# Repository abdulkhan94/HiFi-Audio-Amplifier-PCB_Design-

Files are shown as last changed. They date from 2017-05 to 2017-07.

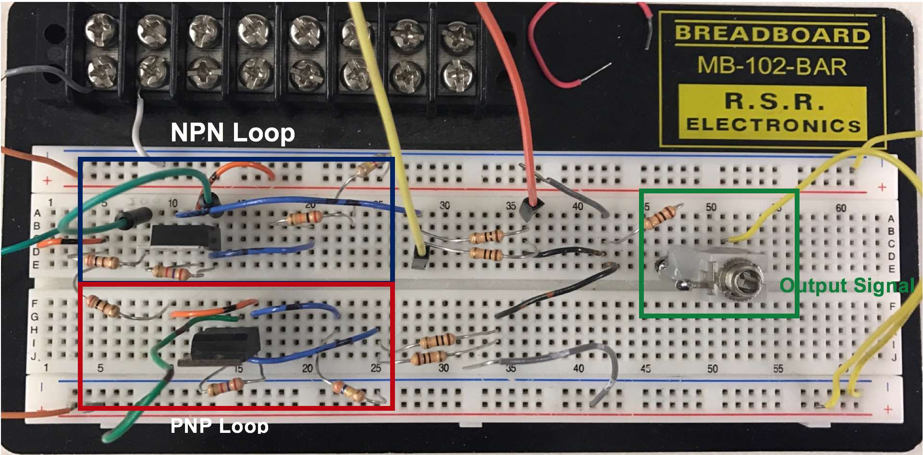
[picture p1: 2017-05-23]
Documents & Simulations/FDR/Proto_anote_v2.png

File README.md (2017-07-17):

# Transparent HiFi Audio Amplifier for Headphones
## Introduction
The goal of our Transparent HiFi USB Audio Amplifier system is to take in a audio signal via USB, allow the user to modify amplifier and volume controls, and to hear the modified audio signal through headphones. Our system specifications are for our design to not produce a DC offset that’s greater than 20mV, to not produce excessive power spikes greater than 50mV, have an output impedance of less than 2 ohms, and to support 8 specific headphones with a range of impedances from 16 to 600 ohms. The left and right audio signals must have flat frequency responses (+/-2.5dB), linear/flat phase responses without being set at 0dB, noise under -105dBv (-103dBu) and distortion under 1% THd into 150 ohms at 1Vrms. Lastly, the power amplifier must have a slew of under 3V/us by a square wave of 600 ohms. 

## Power Amplifier
The power amplifier subsystem will get a 1 V pk-pk signal input from the Amplifier controls subsystem and will amplify that to output analog audio signal across various headphones. All parts of the subsystem will be powered by +13/-13 DC Voltage signal. The subsystem consists of two different parts to achieve amplification of both current and voltage.
The first stage of the design consists of a preamplifier design. This is essentially a Class A audio amplifier which is implemented in order to boost the voltage of the 1 V pk-pk signal that the subsystem receives as input from the amplifier controls subsystem. A major design consideration that has been made here revolves around amplifying voltage to the adequate level while maintaining low noise in the signal. The design consists of two biasing resistors followed by a NPN transistor. This part of the design is powered by a +13V DC power rail. 
The next step of the design consists of the power amplifier which amplifies the current. This part of the subsystem is required to have enough current in order to drive the output across the headphones. A class AB amplifier design has been implemented here in order to achieve the adequate current amplification. This design also consists of two biasing resistors for each transistor and is powered by +/- 13V DC power rails.

## Current Status
* All subsytems of the design have been finalised and layed out on PCB's. 
* All subsystems integrated and fully functional.

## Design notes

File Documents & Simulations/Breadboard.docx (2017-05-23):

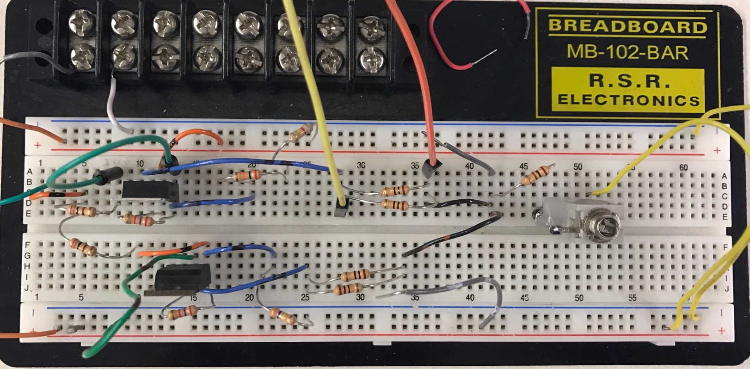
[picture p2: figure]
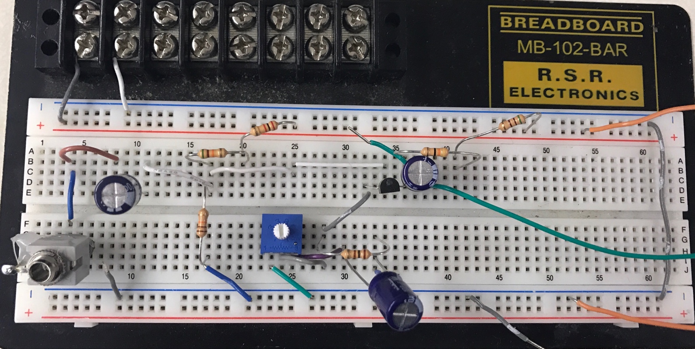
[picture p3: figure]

Output Signal

PNP Loop

NPN Loop

Input Signal

Bias Resistors

Output to 2nd Stage

NPN Transistor

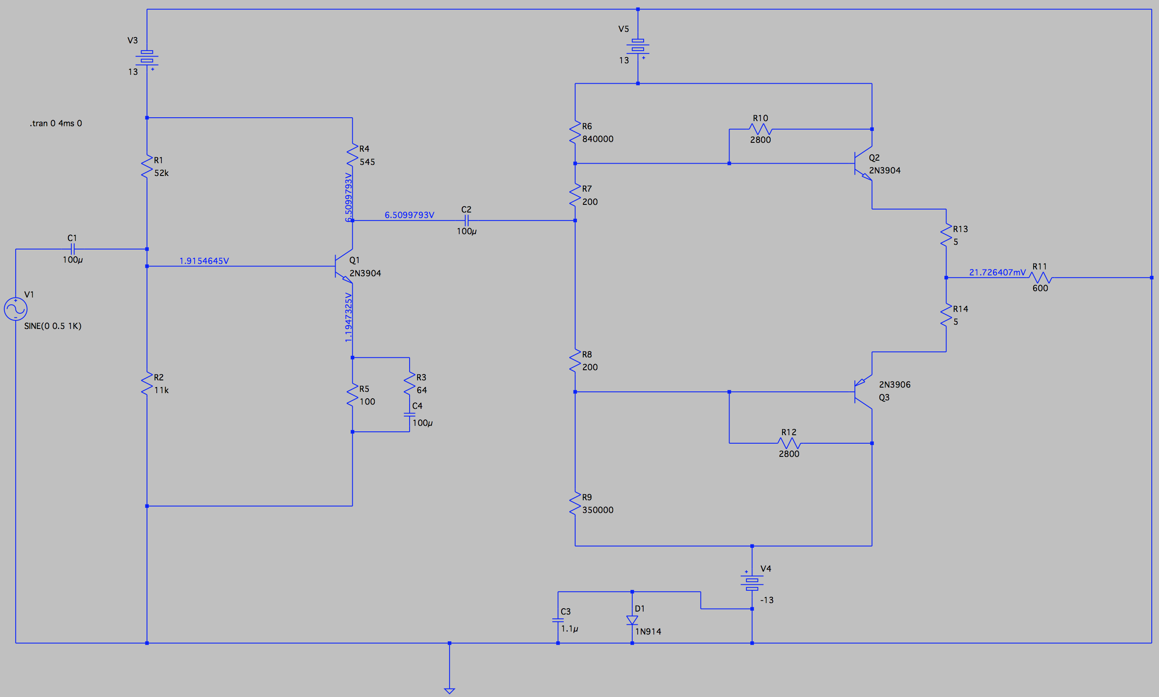
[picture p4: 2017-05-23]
Documents & Simulations/ManagerMeeting2/Schematic_final.png

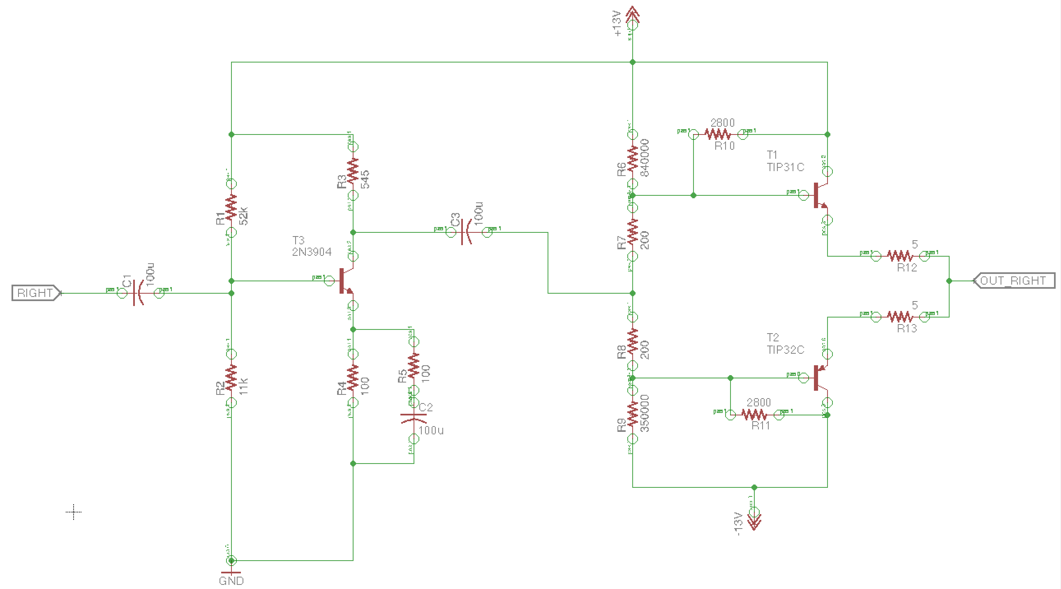
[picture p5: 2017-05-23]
Documents & Simulations/FDR/Final_Schematic.png

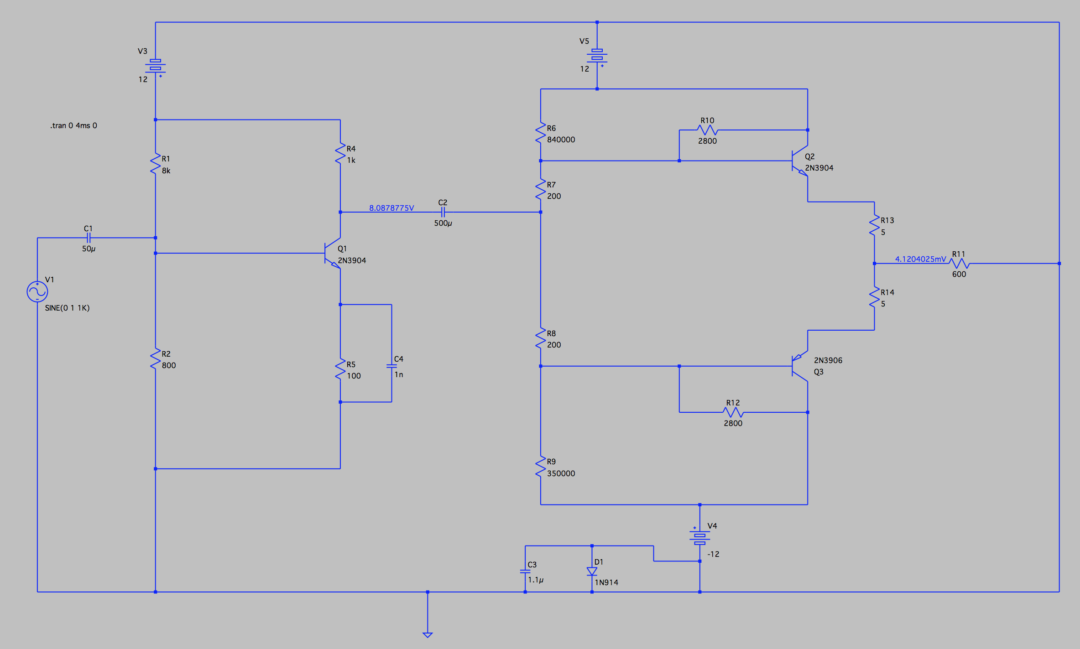
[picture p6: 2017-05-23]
Documents & Simulations/Schematic_v2.png

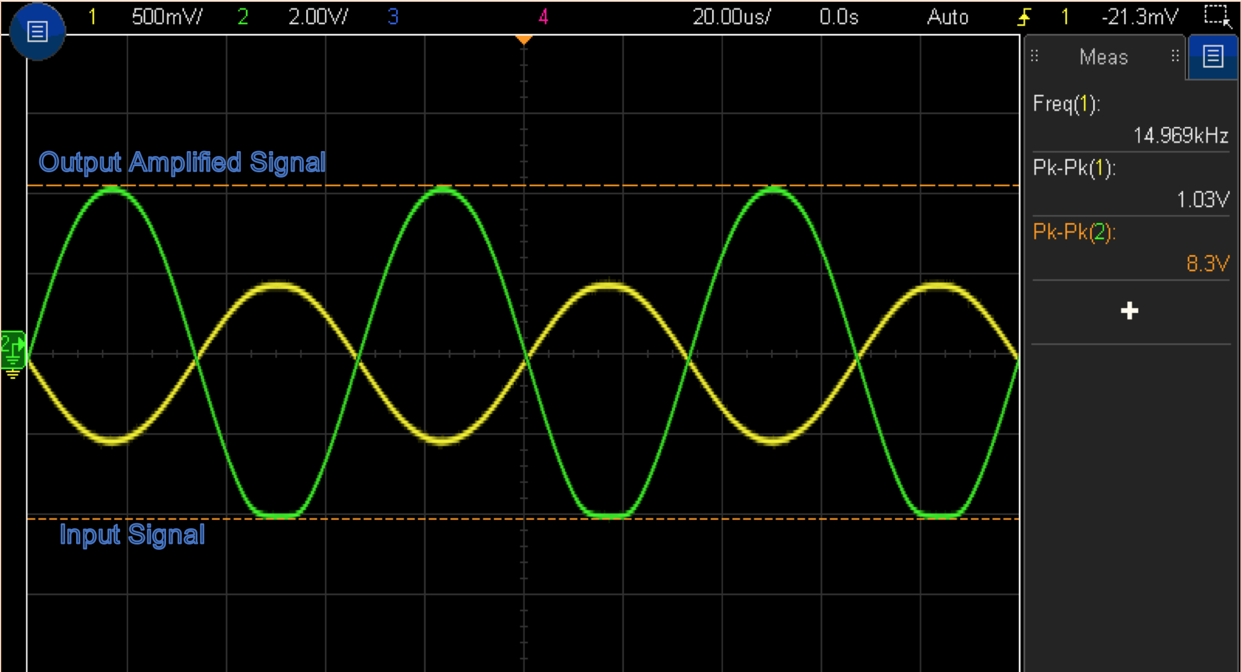
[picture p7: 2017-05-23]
Documents & Simulations/FDR/PowerAmp_15Khhz.png

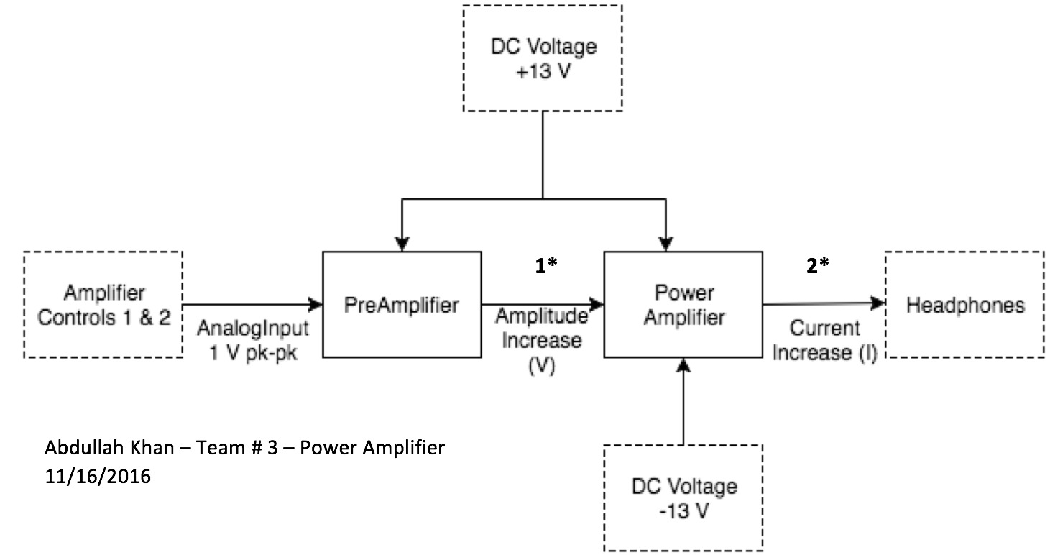
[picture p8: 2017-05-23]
Documents & Simulations/FDR/Block.png

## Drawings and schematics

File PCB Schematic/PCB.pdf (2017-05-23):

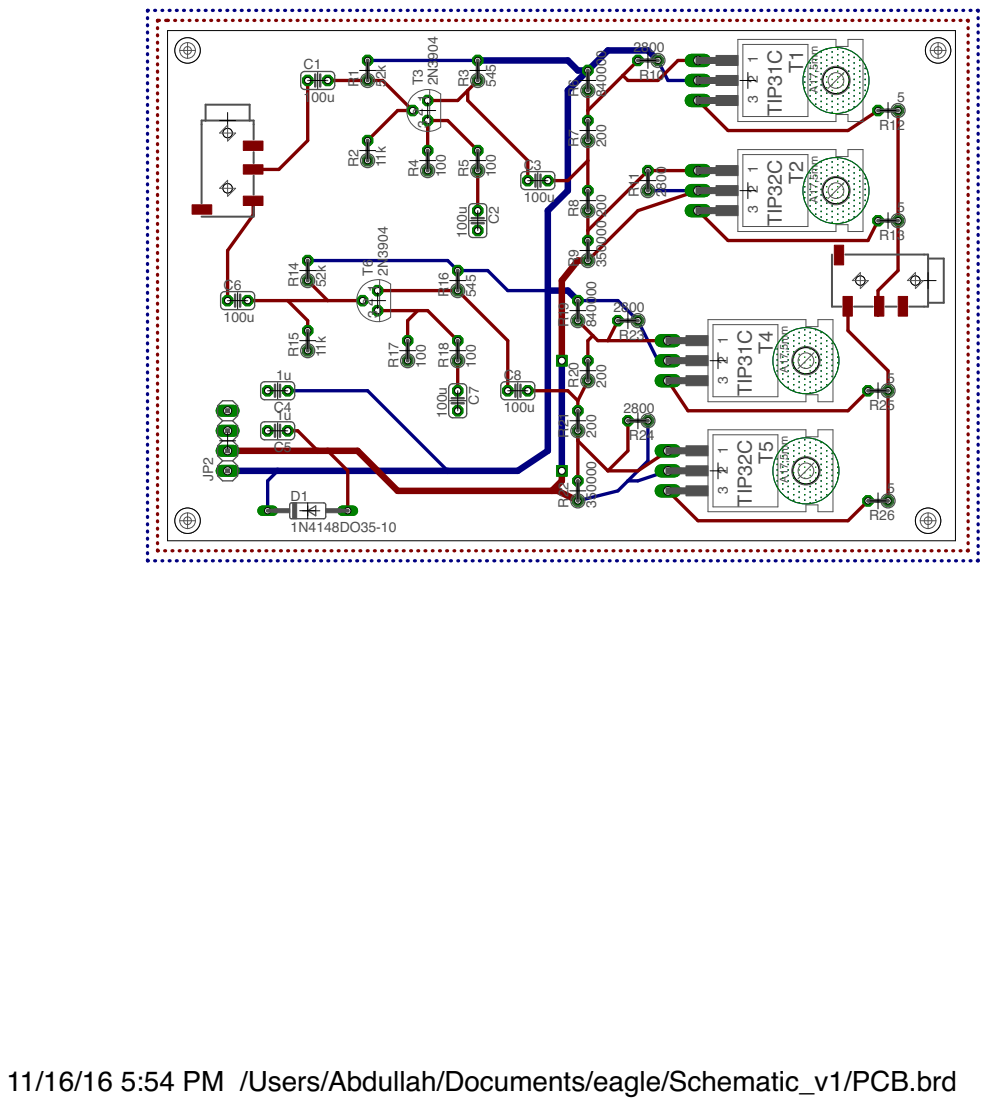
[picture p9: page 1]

11/16/16 5:54 PM /Users/Abdullah/Documents/eagle/Schematic_v1/PCB.brd

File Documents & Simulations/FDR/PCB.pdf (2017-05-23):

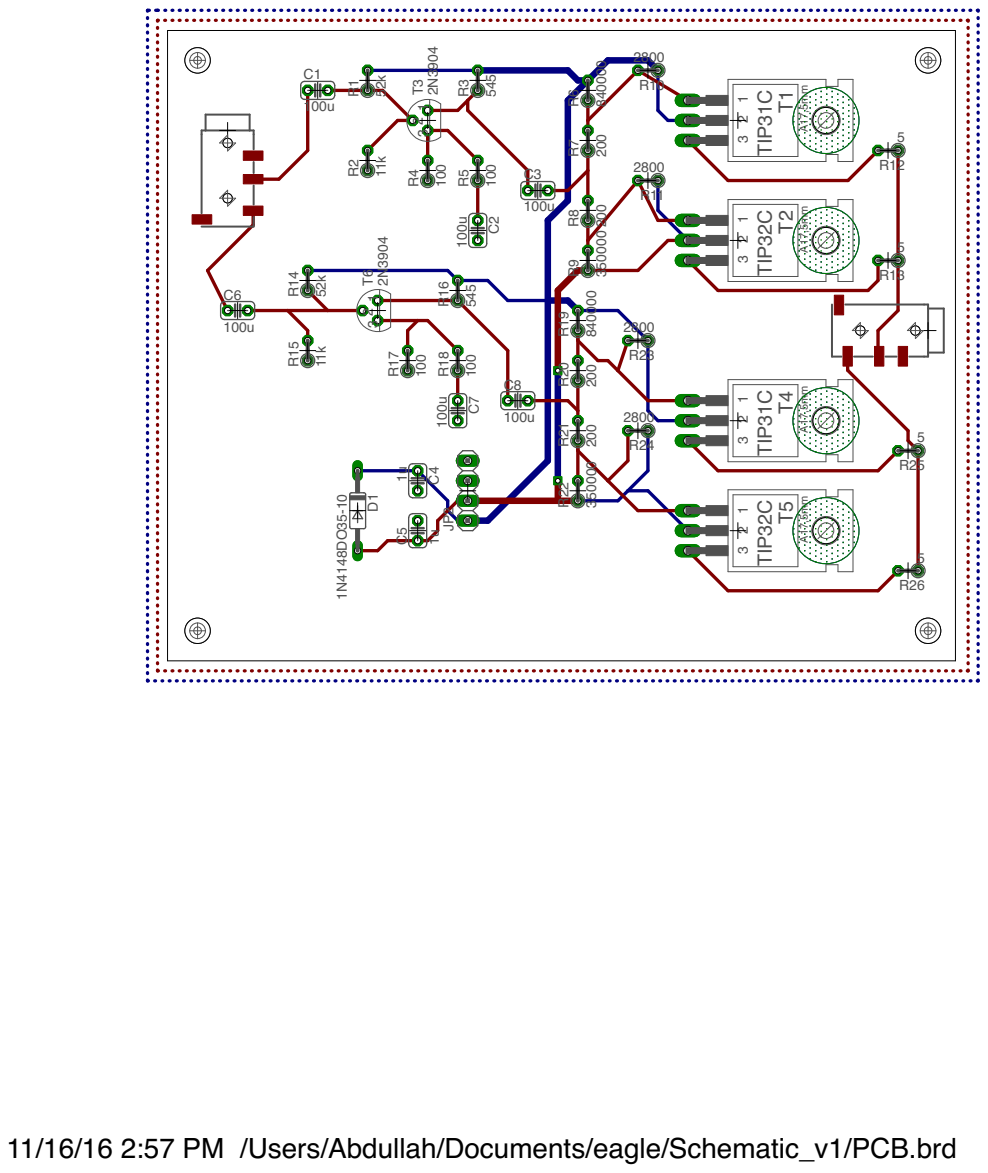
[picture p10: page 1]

11/16/16 2:57 PM /Users/Abdullah/Documents/eagle/Schematic_v1/PCB.brd

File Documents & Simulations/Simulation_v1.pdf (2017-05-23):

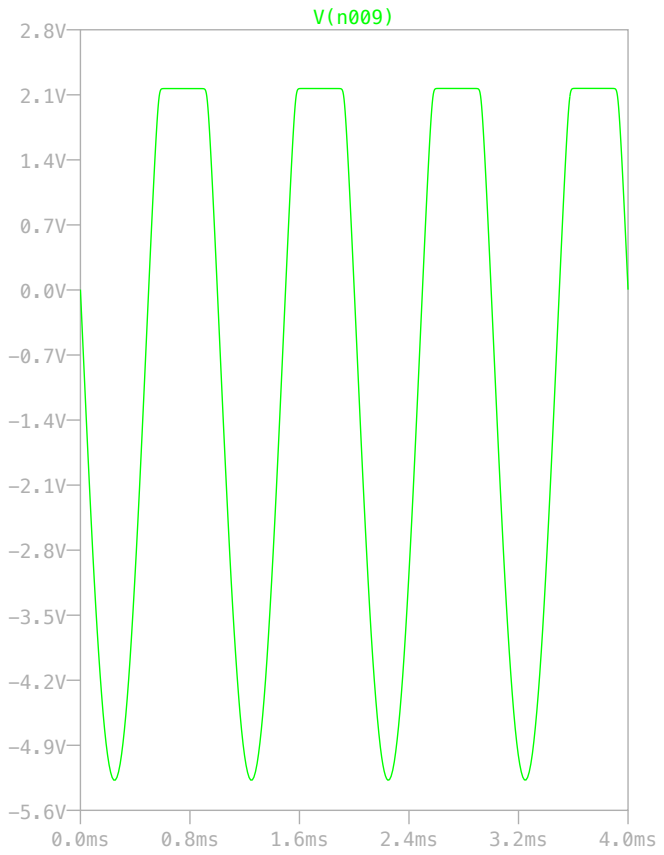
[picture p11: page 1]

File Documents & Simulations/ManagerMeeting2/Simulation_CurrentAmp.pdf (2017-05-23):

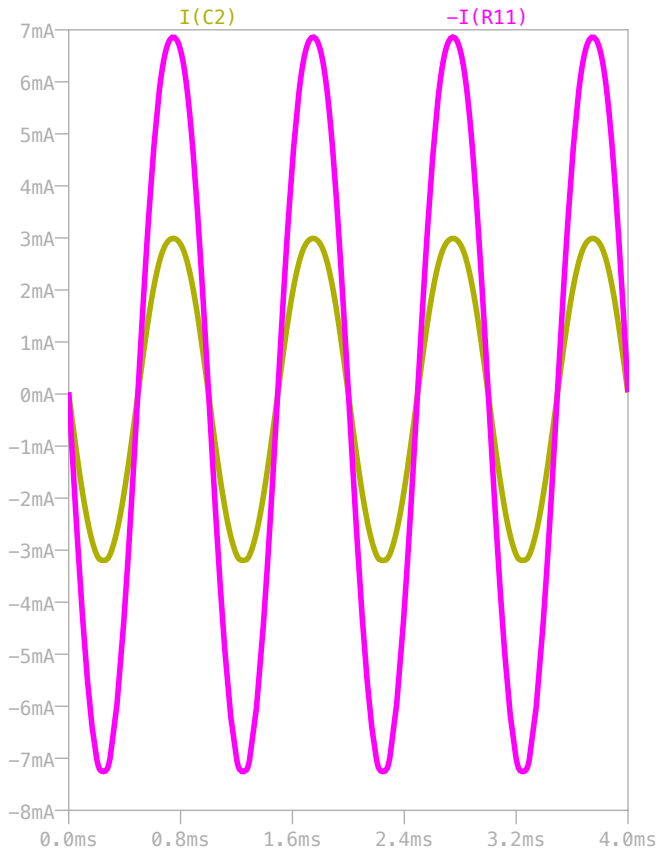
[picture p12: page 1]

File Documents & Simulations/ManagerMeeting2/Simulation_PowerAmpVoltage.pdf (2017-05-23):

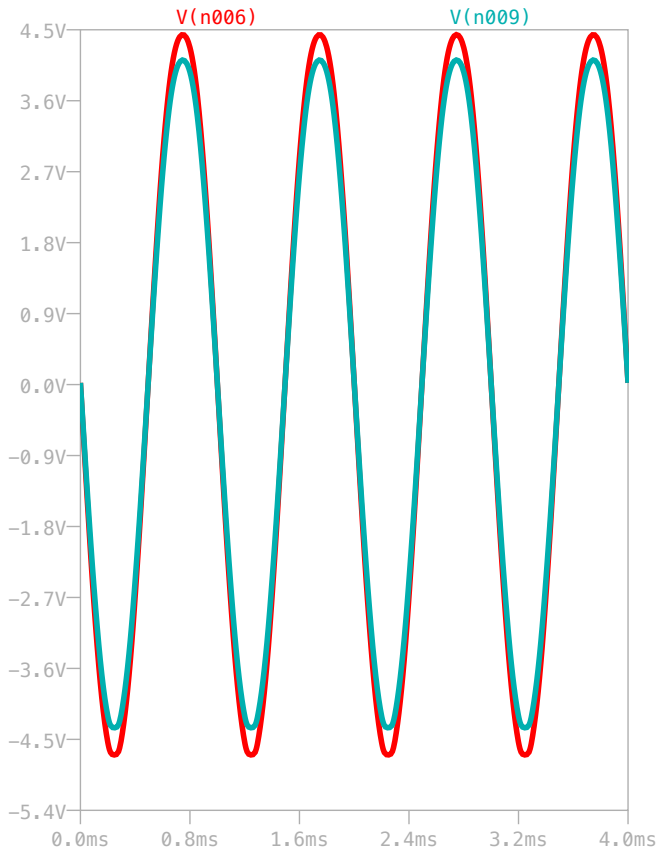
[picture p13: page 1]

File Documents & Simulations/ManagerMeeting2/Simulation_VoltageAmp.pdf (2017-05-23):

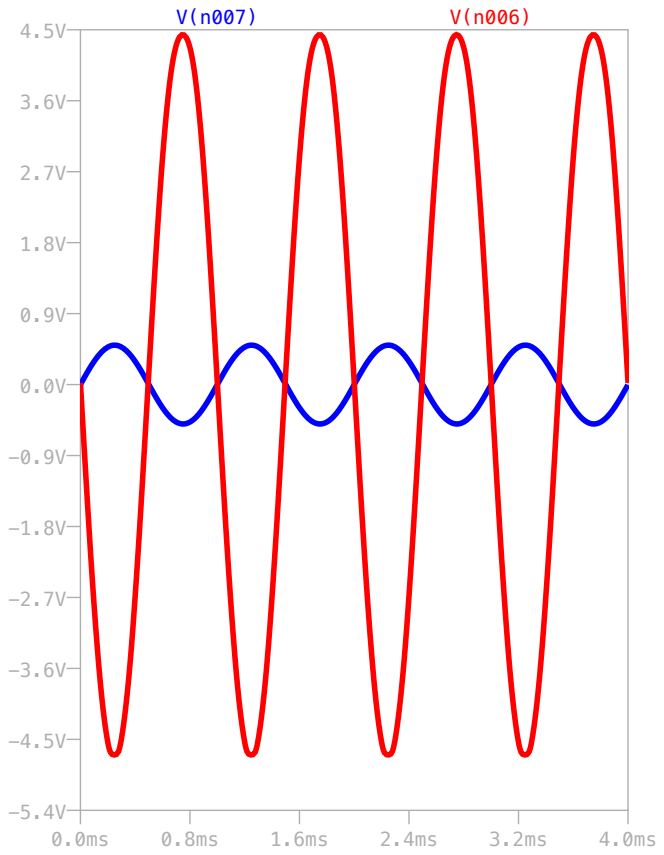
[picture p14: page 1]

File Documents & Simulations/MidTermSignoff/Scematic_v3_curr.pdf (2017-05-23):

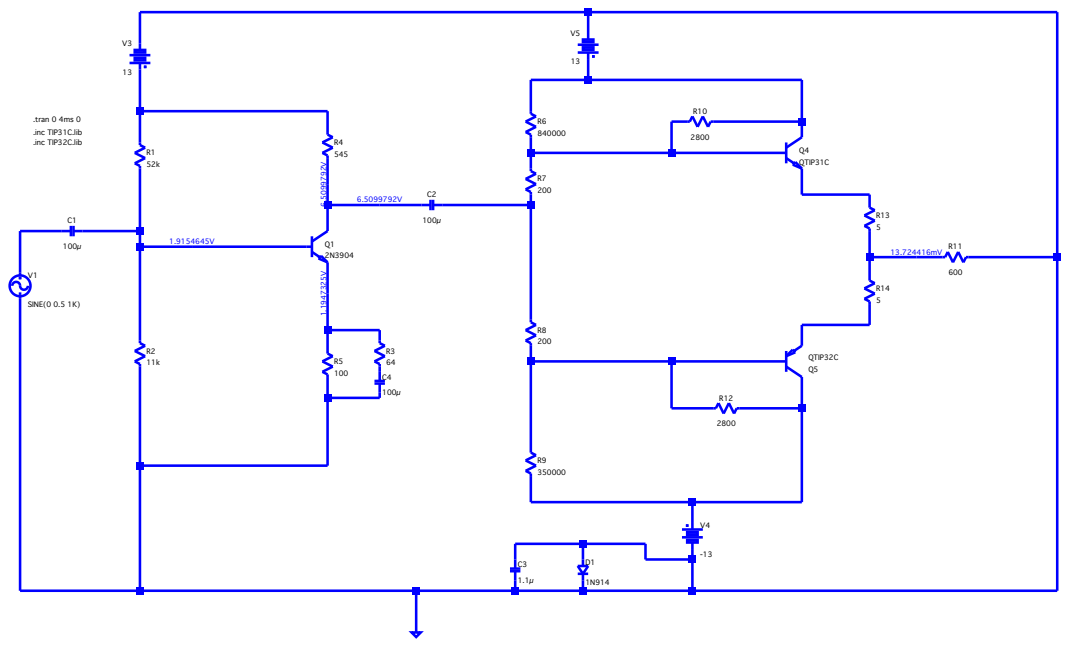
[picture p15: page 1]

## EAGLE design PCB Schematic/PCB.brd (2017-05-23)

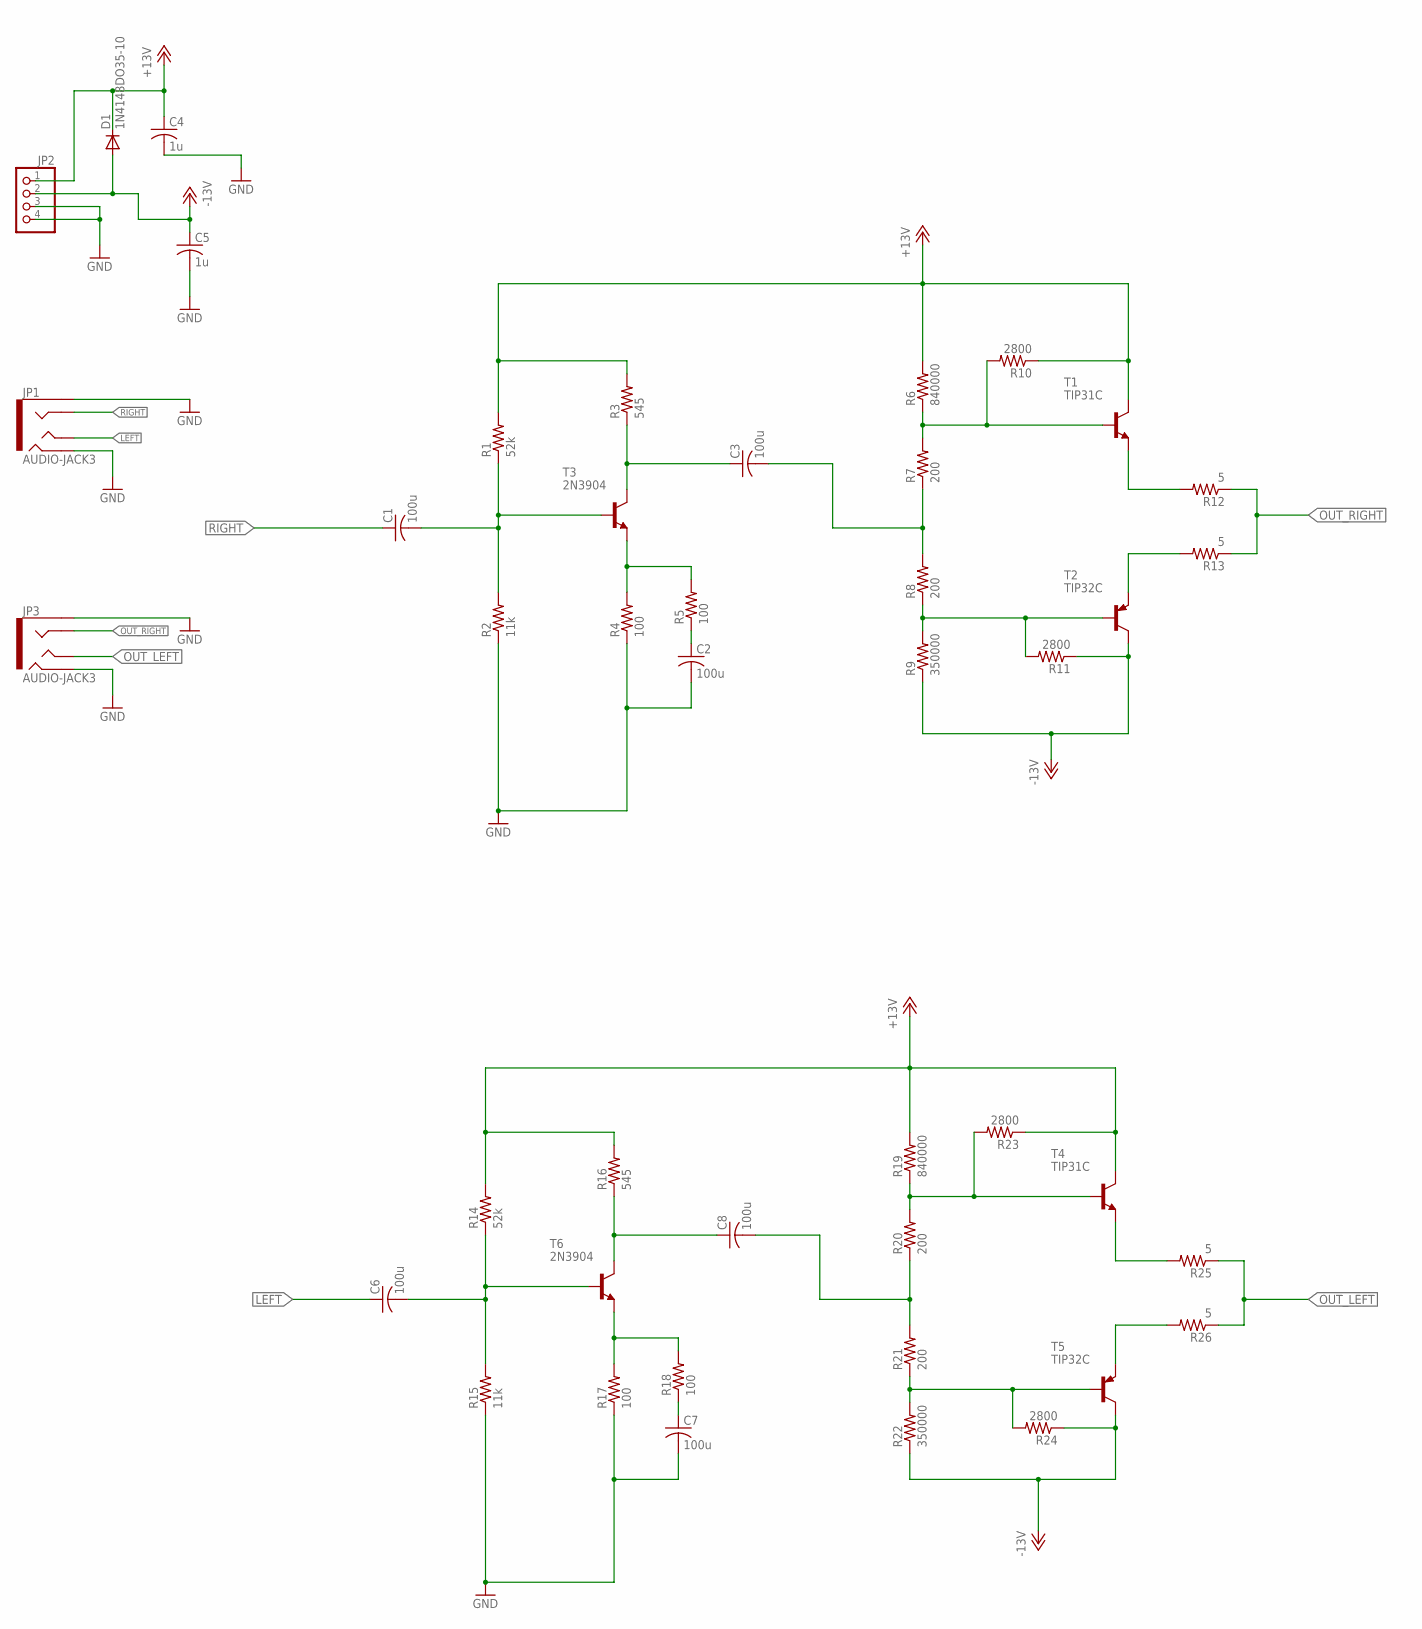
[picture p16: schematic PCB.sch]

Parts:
C1, C2, C3, C6, C7, C8: 100u; C025-024X044
C4, C5: 1u; C025-024X044
D1: 1N4148DO35-10; DO35-10
JP1, JP3: AUDIO-JACK3; AUDIO-JACK-TRRS-SMD
JP2: PINHD-1X4; 1X04
R1, R14: 52k; 0204V
R2, R15: 11k; 0204V
R3, R16: 545; 0204V
R4, R5, R17, R18: 100; 0204V
R6, R19: 840000; 0204V
R7, R8, R20, R21: 200; 0204V
R9, R22: 350000; 0204V
R10, R11, R23, R24: 2800; 0204V
R12, R13, R25, R26: 5; 0204V
T1, T4: TIP31C; TO220
T2, T5: TIP32C; TO220
T3, T6: 2N3904; TO92

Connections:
+13V: C4.1, D1.C, JP2.1, R1.2, R3.2, R6.2, R10.1, R14.2, R16.2, R19.2, R23.1, T1.2 (C), T4.2 (C)
-13V: C5.1, D1.A, JP2.2, R9.1, R11.1, R22.1, R24.1, T2.2 (C), T5.2 (C)
GND: C2.2, C4.2, C5.2, C7.2, JP1.EARTH, JP1.RING2, JP2.3, JP2.4, JP3.EARTH, JP3.RING2, R2.1, R4.1, R15.1, R17.1
LEFT: C6.1, JP1.TIP
unnamed: C1.2, R1.1, R2.2, T3.2 (B)
unnamed: C3.1, R3.1, T3.1 (C)
unnamed: C6.2, R14.1, R15.2, T6.2 (B)
unnamed: R4.2, R5.2, T3.3 (E)
unnamed: R6.1, R7.2, R10.2, T1.1 (B)
unnamed: C2.1, R5.1
unnamed: C3.2, R7.1, R8.2
unnamed: R8.1, R9.2, R11.2, T2.1 (B)
unnamed: R12.2, T1.3 (E)
unnamed: R13.2, T2.3 (E)
unnamed: C8.1, R16.1, T6.1 (C)
unnamed: R17.2, R18.2, T6.3 (E)
unnamed: C7.1, R18.1
unnamed: R19.1, R20.2, R23.2, T4.1 (B)
unnamed: C8.2, R20.1, R21.2
unnamed: R21.1, R22.2, R24.2, T5.1 (B)
unnamed: R25.2, T4.3 (E)
unnamed: R26.2, T5.3 (E)
OUT_LEFT: JP3.TIP, R25.1, R26.1
OUT_RIGHT: JP3.RING1, R12.1, R13.1
RIGHT: C1.1, JP1.RING1

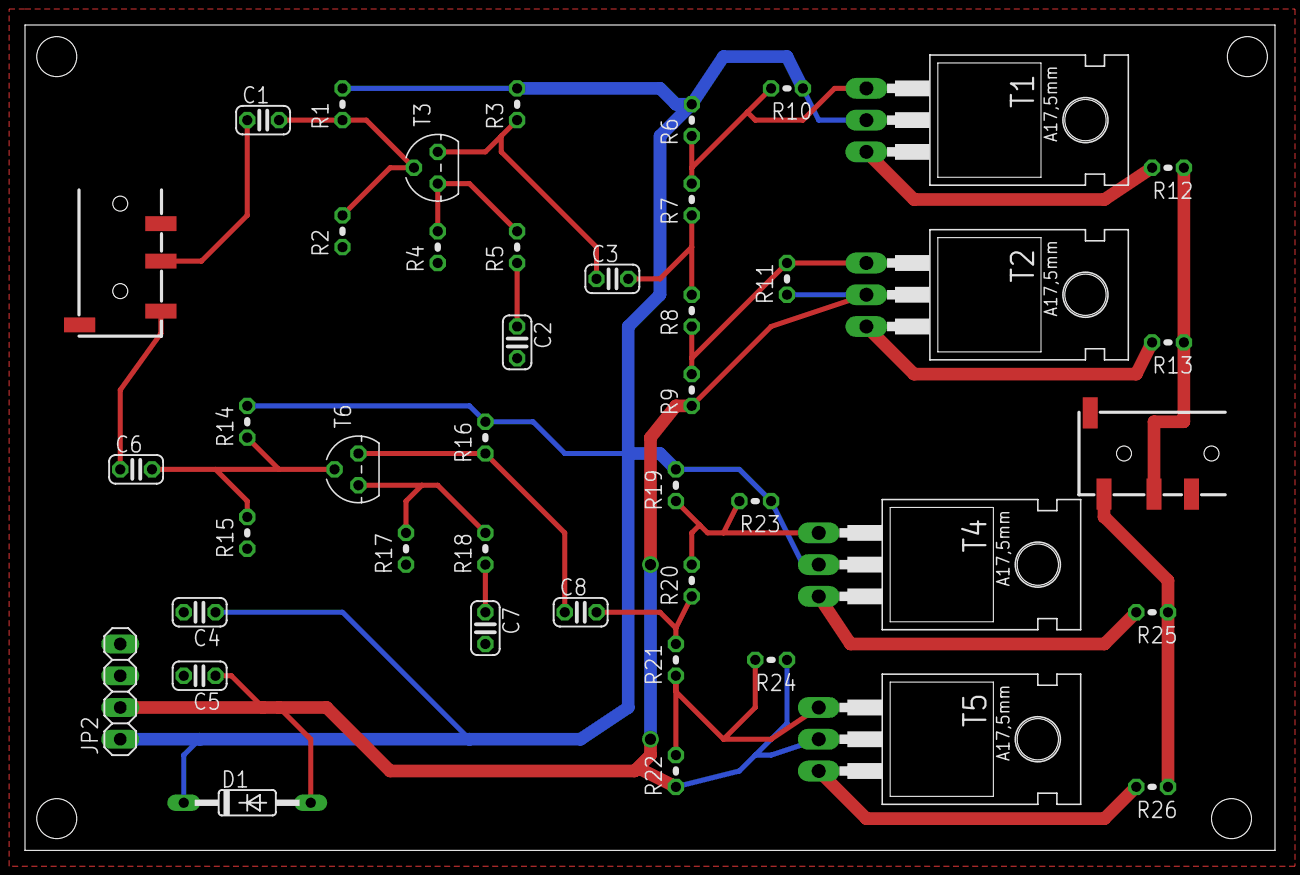
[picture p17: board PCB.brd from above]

Board: 2 copper layers, 100.0 x 66.0 mm, 44 parts (0 on the bottom side), 25 nets.

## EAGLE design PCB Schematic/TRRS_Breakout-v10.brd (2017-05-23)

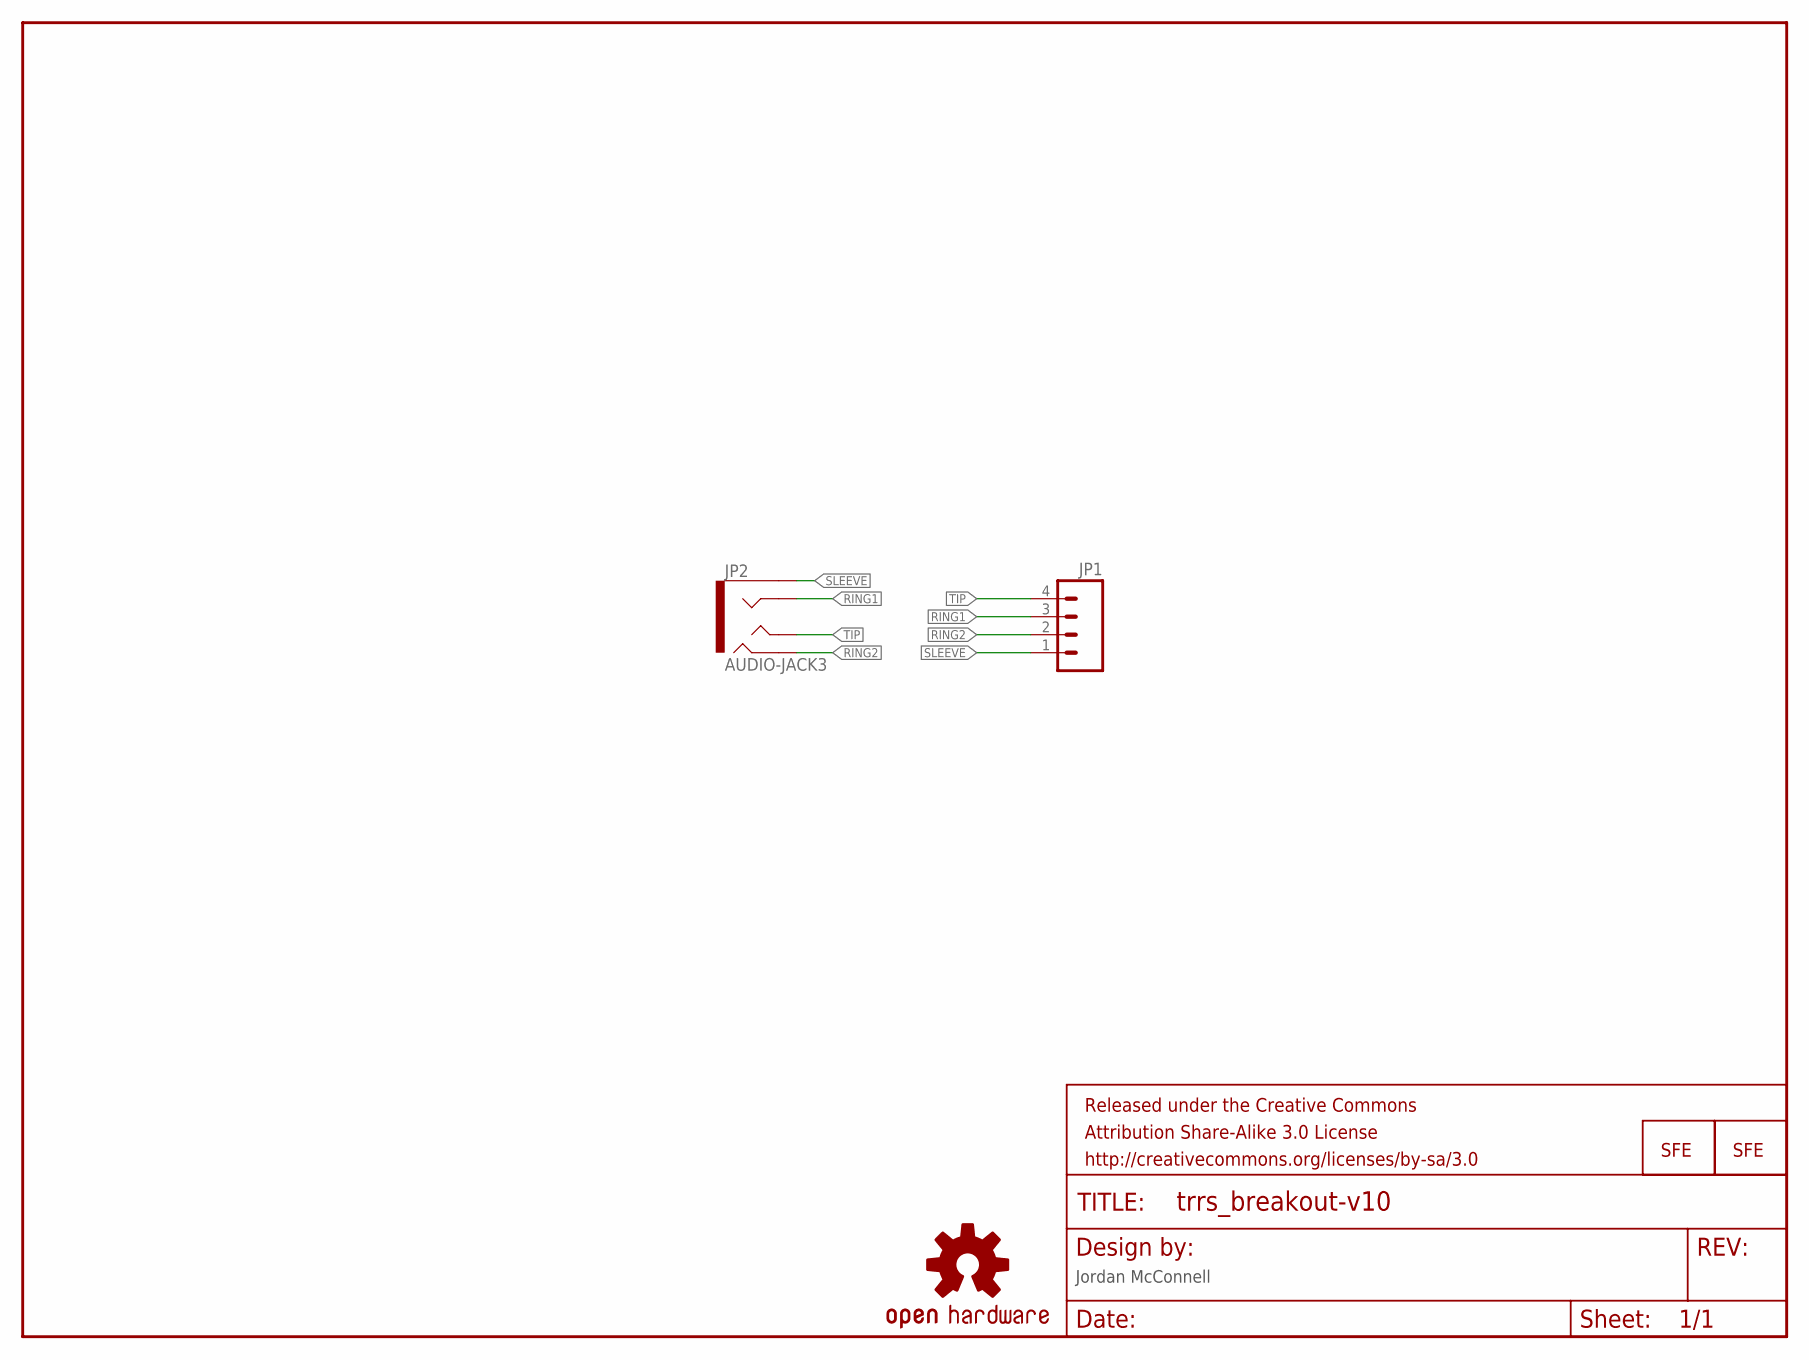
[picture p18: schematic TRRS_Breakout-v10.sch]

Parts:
FRAME1: FRAME-LETTER; CREATIVE_COMMONS
JP1: M04PTH; 1X04
JP2: AUDIO-JACK3; AUDIO-JACK-TRRS-SMD
JP3, JP4: LOGO-SFESK; SFE-LOGO-FLAME
U$1: OSHW-LOGOS; OSHW-LOGO-S

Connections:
RING1: JP1.3, JP2.RING1
RING2: JP1.2, JP2.RING2
SLEEVE: JP1.1, JP2.EARTH
TIP: JP1.4, JP2.TIP

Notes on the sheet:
Jordan McConnell

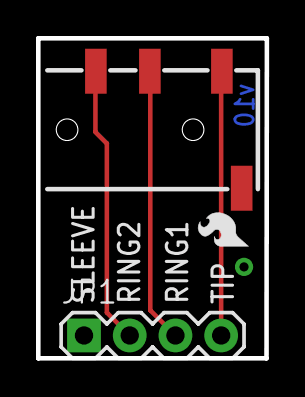
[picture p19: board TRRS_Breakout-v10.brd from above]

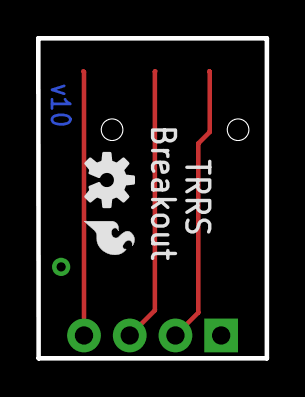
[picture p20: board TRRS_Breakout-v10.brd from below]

Board: 2 copper layers, 12.7 x 17.8 mm, 6 parts (2 on the bottom side), 4 nets.

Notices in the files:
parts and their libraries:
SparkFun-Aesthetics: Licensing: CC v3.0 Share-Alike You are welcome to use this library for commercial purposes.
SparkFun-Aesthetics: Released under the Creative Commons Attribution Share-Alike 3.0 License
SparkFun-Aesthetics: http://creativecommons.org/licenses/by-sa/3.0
